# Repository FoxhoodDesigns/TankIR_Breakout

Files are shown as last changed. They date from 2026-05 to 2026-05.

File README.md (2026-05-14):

Miniature TankIR shield. Intended to be attached on top of a Arduino Nano for compact size
Components are identical to regular TANKIR schematic in regards of transistor and resistor uses.
For 5V Regulator you can use anything be it a regular 7805 (Inefficient) or one of its many drop-in replacements

Pinouts are largely the same as on Open Panzer. If you face it by its little slot in the middle: The right pin of most JST-SH connectors are the 5V. The left the GND/Open-Collector.
Servo and RC are slightly annoying. A tiny + at the corner indicates the Signal pin

Please note that this board lacks extra Servo outputs and a Button Trigger to save space. This is meant to be triggered by other control boards or (with a little bit of work on the code:) Potentially a RC Input

REVISION 2: Based on feedback. Tolerances have been greatly increased to avoid issues with fabs and accidental shorts. This new board is identified by a REV2 in the corner.

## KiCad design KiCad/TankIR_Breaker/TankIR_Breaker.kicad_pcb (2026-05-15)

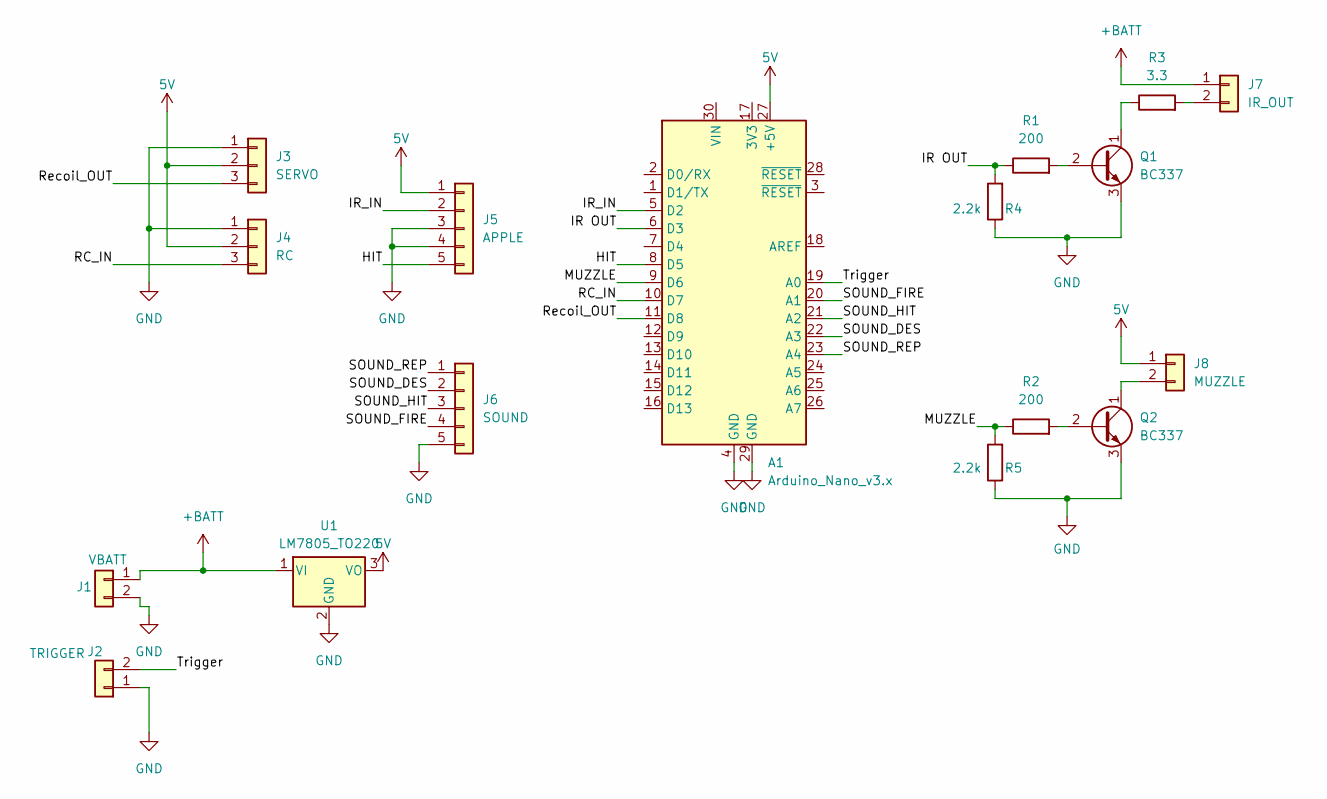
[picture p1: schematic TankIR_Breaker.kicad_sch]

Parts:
A1: Arduino_Nano_v3.x; Arduino_Nano
J1: VBATT; JST_PH_B2B-PH-K_1x02_P2.00mm_Vertical
J2: TRIGGER; JST_PH_B2B-PH-K_1x02_P2.00mm_Vertical
J3: SERVO; PinHeader_1x03_P2.54mm_Vertical
J4: RC; PinHeader_1x03_P2.54mm_Vertical
J5: APPLE; JST_PH_B5B-PH-K_1x05_P2.00mm_Vertical
J6: SOUND; PinHeader_1x05_P2.54mm_Vertical
J7: IR_OUT; JST_PH_B2B-PH-K_1x02_P2.00mm_Vertical
J8: MUZZLE; JST_PH_B2B-PH-K_1x02_P2.00mm_Vertical
Q1, Q2: BC337; TO-92_Inline
R1, R2: 200; R_Axial_DIN0204_L3.6mm_D1.6mm_P2.54mm_Vertical
R3: 3.3; R_Axial_DIN0204_L3.6mm_D1.6mm_P2.54mm_Vertical
R4, R5: 2.2k; R_Axial_DIN0204_L3.6mm_D1.6mm_P2.54mm_Vertical
U1: LM7805_TO220; TO-220-3_Vertical

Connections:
5V: A1.27 (+5V), J3.2, J4.2, J5.1, J8.1, U1.3 (VO)
+BATT: J1.1, J7.1, U1.1 (VI)
/HIT: A1.8 (D5), J5.5
/IR OUT: A1.6 (D3), R1.1, R4.2
/IR_IN: A1.5 (D2), J5.2
/MUZZLE: A1.9 (D6), R2.1, R5.2
/RC_IN: A1.10 (D7), J4.3
/Recoil_OUT: A1.11 (D8), J3.3
/SOUND_DES: A1.22 (A3), J6.2
/SOUND_FIRE: A1.20 (A1), J6.4
/SOUND_HIT: A1.21 (A2), J6.3
/SOUND_REP: A1.23 (A4), J6.1
/Trigger: A1.19 (A0), J2.2
GND: A1.4 (GND), A1.29 (GND), J1.2, J2.1, J3.1, J4.1, J5.3, J5.4, J6.5, Q1.3 (E), Q2.3 (E), R4.1, R5.1, U1.2 (GND)
unnamed: J7.2, R3.2
unnamed: J8.2, Q2.1 (C)
unnamed: Q1.2 (B), R1.2
unnamed: Q1.1 (C), R3.1
unnamed: Q2.2 (B), R2.2

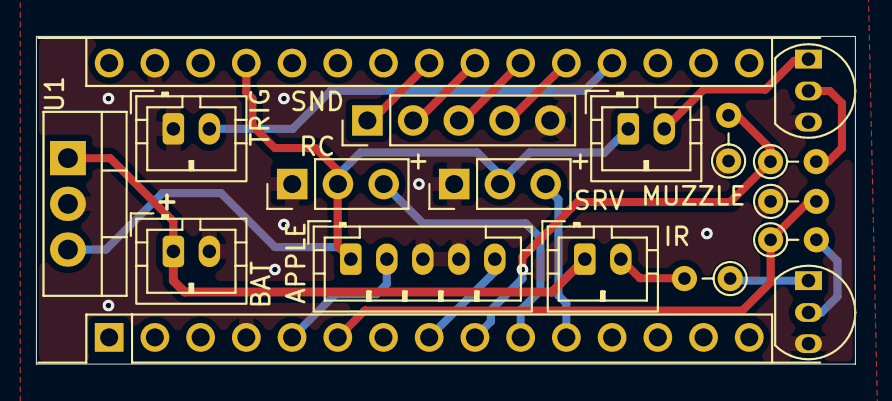
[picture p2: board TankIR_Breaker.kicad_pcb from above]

Board: 2 copper layers, 45.5 x 18.2 mm, 17 parts (0 on the bottom side), 19 nets.

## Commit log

2026-02-19 Initial Upload
    Initial Push
    [TankIR_Breaker-B_Cu.gbr, TankIR_Breaker-B_Mask.gbr, TankIR_Breaker-B_Paste.gbr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]
2026-02-19 fix
    Fixed missing 5V connection
    [TankIR_Breaker-B_Cu.gbr, TankIR_Breaker-B_Mask.gbr, TankIR_Breaker-B_Paste.gbr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]
2026-05-14 REV2
    Modified board for more reliable fabrication and added Pull-down resistors to avoid Transistor current leakage
    [TankIR_Breaker-B_Cu.gbr, TankIR_Breaker-B_Mask.gbr, TankIR_Breaker-B_Paste.gbr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]
